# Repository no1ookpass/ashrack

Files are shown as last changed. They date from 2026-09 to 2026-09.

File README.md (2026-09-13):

# Ashrack

An open source, modular half-rack system for 19" racks. Every module is half a
rack wide and slides into the rack from the front, and each one holds a tray that
slides into it, so the tray can be built to suit whatever goes inside.

## Files

| File | What it is |
|---|---|
| `ashrack-panel.scad` | The front module: panel, mounting ear with the rack screw holes, the skeleton frame that holds a tray, and the joiner tabs |
| `ashrack-tray.scad` | The tray that slides into a module: front face with cut-outs, floor with PCB mounts, styled walls, and an optional removable top |
| `ashrack-common.scad` | Shared rack standards, material and fit dimensions. Included by both parts, so a tray cannot drift out of fit with its module |
| `LICENSE` | MIT, so use it, change it and sell it. The only condition is that the notice travels with the files |

Open either part in OpenSCAD and use the Customizer panel; everything you can
change is listed there. The two parts are separate files, but they include the
same dimension file, so build them with matching `module_units`, `tray_width`
and `tray_depth`. Every file is named `ashrack-`, so the project's parts sort
together in a listing and can't be mistaken for a `tray.scad` from elsewhere.

## How the two halves work

A module is half a 19" rack (241.3 mm), so two of them sit side by side and meet
flush in the middle. Both hands come from one model: set `side` to `left` or
`right` and the body is mirrored with a transform, so there is no second file.

At the non-mounting edge each module has a pair of joiner tabs. The right hand's
pair sits one thickness higher, so the two interleave into a four tab stack that
a single vertical bolt passes through, tying the halves together.

Because a module is really just a slot, the two halves need not match. Each takes
its own `tray_width` and `tray_depth`, so a wide deep tray and a narrow shallow
one can sit side by side in the same rack space — the paired examples below do
exactly that.

## Module inputs (`ashrack-panel.scad`)

| Input | Meaning | Default |
|---|---|---|
| `module_units` | Height in rack units | 2 |
| `tray_offset` | How far the tray slot sits from the mounting edge | 20 mm |
| `tray_depth` | How deep a tray the slot takes | 150 mm |
| `tray_width` | Tray width. **0 prints a blank panel**, with no slot at all | 150 mm |
| `side` | Which hand to build | left |
| `ear_thickness` | Mounting ear thickness, as a multiple of the panel | 5 |
| `screw_holes` | Rack screws per unit: 1 centre, 2 outer pair, 3 all three | 3 |

Rack screw holes follow EIA-310: 6.35, 22.225 and 38.1 mm above each unit's
lower edge, so the outer holes sit near the panel edges.

## Tray inputs (`ashrack-tray.scad`)

| Input | Meaning | Default |
|---|---|---|
| `module_units`, `tray_width`, `tray_depth` | Must match the module it goes in | 2, 150, 150 |
| `side_style`, `back_style`, `top_style` | `solid`, `slits` or `skeleton` for each wall | skeleton |
| `top_removable` | Build the top in, or print it as its own part | false |
| `part` | Which piece to build: `body` or `top` | body |
| `handle_sides` | `none`, `rail`, `centre` or `both` | none |
| `handle_type` | `loop` (upright half donut pull) or `knob` | loop |

Handles are named from the module's mounting edge: `rail` is the edge that
screws to the rack, `centre` faces the middle of the rack. Left and right flip
with the hand, so they are no good as names.

### Two lists you edit in the file

The Customizer cannot take a list of shapes: it only accepts flat vectors of up
to four numbers. So the front cut-outs and the floor mounts live in the file,
where they can be any length. Both are commented in place.

```scad
// ["rect", x, z, width, height]  or  ["circle", x, z, diameter, 0]
// (x, z) is the centre, in mm from the bottom left of the front face.
front_cutouts = [
    ["rect",   52, 40, 25, 21],   // ethernet jack
    ["rect",   82, 40, 25, 21],   // ethernet jack
    ["circle", 105, 40,  8,  0],  // LED
];

// [x, y], then height, boss diameter and screw as you need them
pcb_mounts = [[12, 12], [138, 12], [12, 60, 10], [138, 60, 10]];
```

Keep cut-outs clear of the handles: a handle sits `HANDLE_INSET` in from its
edge and half way up the face, and blocks a band around that point — roughly
+/- 4 mm across and +/- 14 mm up and down — and there is no guard against the two
colliding.

`tray()` also takes the two lists, the two handle settings and the two roof settings as arguments —
`cutouts`, `mounts`, `handle_sides`, `handle_type`, `top_style` and `top_removable` — so a build
script can hand over its own without touching this file's defaults:

```scad
tray(units = 1, width = 180, depth = 150, cutouts = my_cutouts, mounts = my_mounts,
     handle_sides = "rail", handle_type = "loop", top_removable = true);
```

That is how a downstream project keeps its build data in its own repo: define the lists there, hand
them over, and the library stays free of any one build's numbers.

Size the keep-out to the handle you picked: a knob is ~16 mm across, a loop spans
`HANDLE_LOOP_OPENING` plus its feet (28 mm) up and down the face and stands further off
it, so the band a cut-out has to avoid is taller with a loop than the `+/- 14 mm` above
suggests.

## Examples

Everything below is these files with the settings noted. The three scripts in
`examples/` show how the parts go together: one for a pair of modules, one for a
module with its tray, and one for both halves with their trays.

### Module

| | |
|---|---|
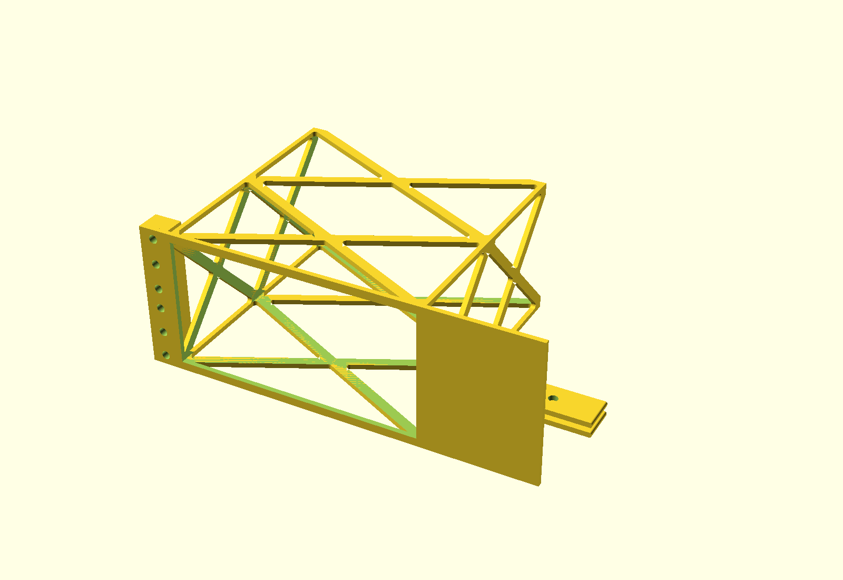
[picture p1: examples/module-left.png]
2U module, left hand
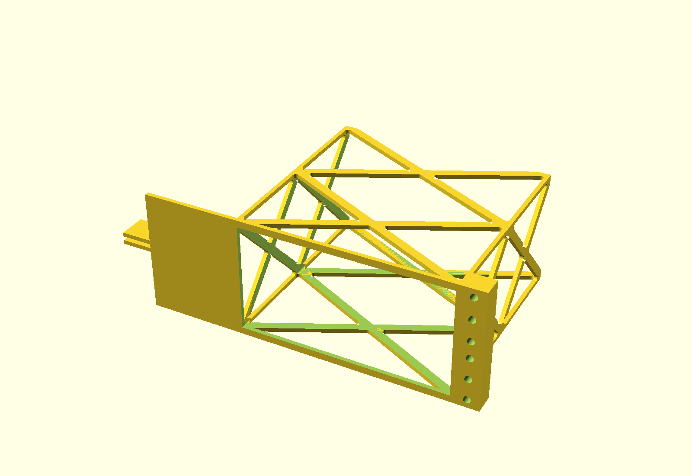
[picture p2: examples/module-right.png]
2U module, right hand
|  |  |
| **Left hand**, the default: mounting ear with the rack screw holes, skeleton tray frame behind the panel | **Right hand**, `side = "right"`. The same model mirrored, so there is no second file |
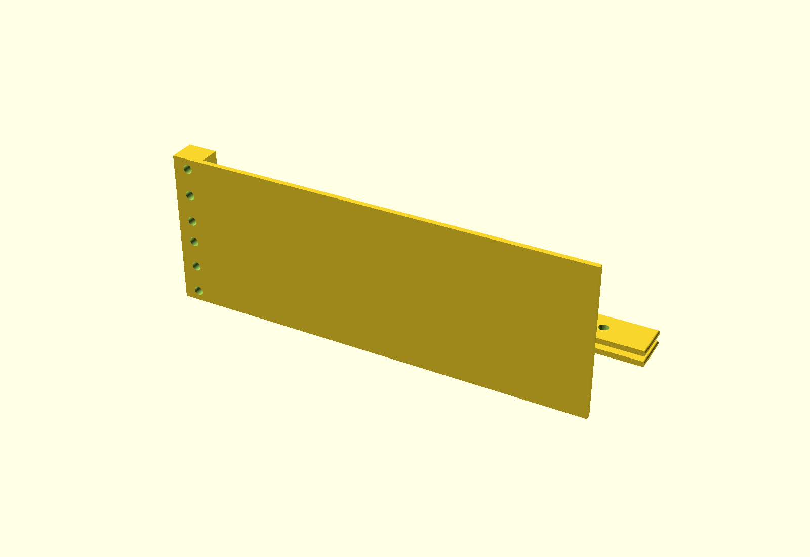
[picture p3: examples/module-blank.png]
Blank panel
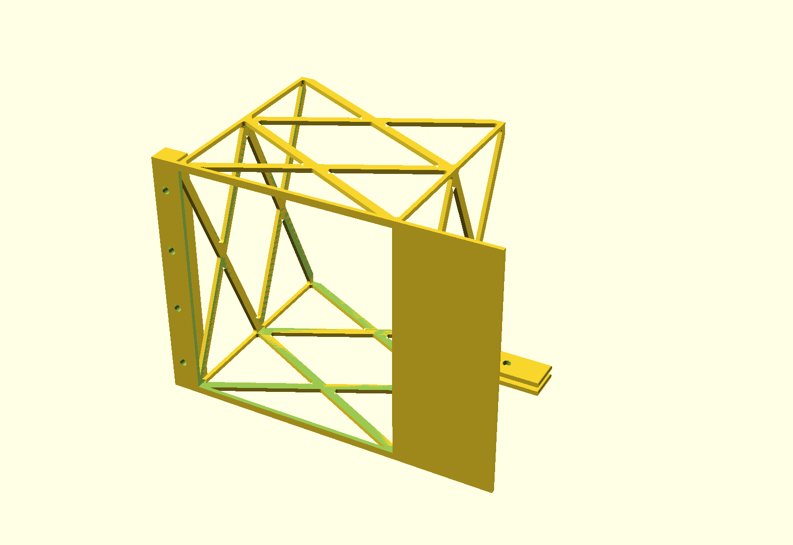
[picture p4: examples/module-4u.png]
4U module, one hole per unit
|  |  |
| `tray_width = 0`: a **blank panel**, no slot and no frame at all | `module_units = 4` with `screw_holes = 1`: one centre hole per unit |
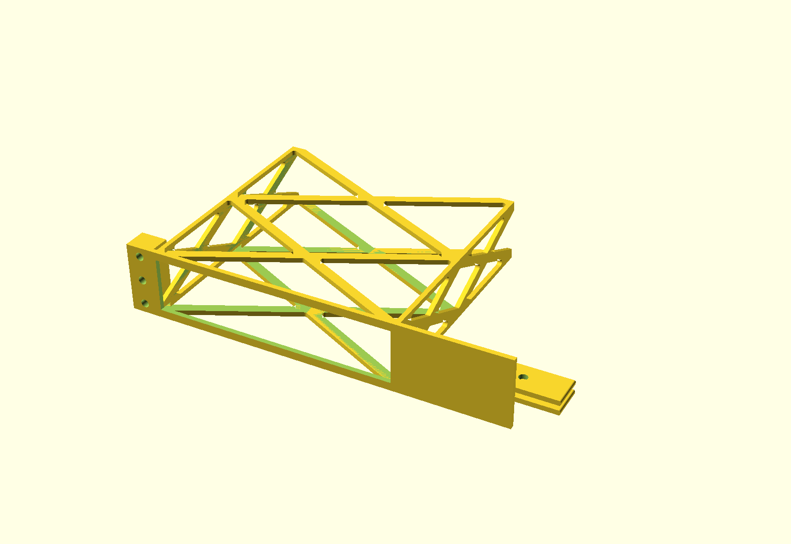
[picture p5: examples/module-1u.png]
1U module
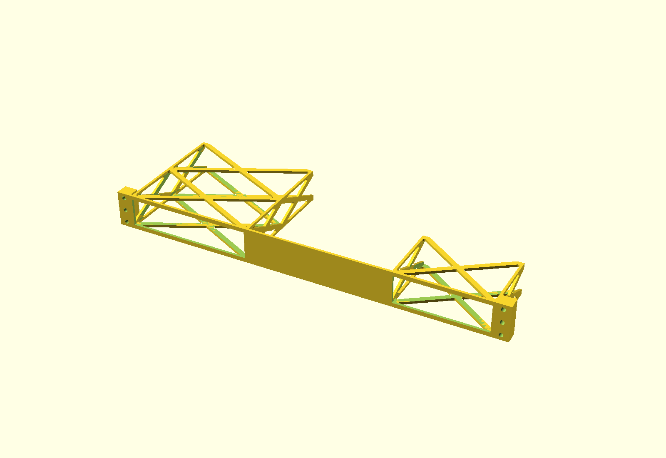
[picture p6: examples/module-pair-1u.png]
Two 1U halves joined
|  |  |
| `module_units = 1`: a single unit tall | The pair again at 1U, still with two different slot sizes |

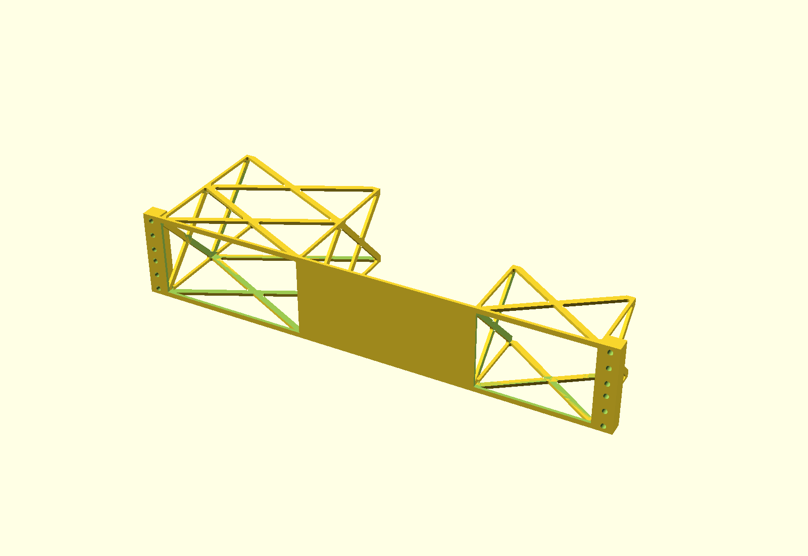
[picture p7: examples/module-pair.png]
Two halves joined


*Two halves butted at the centre of the rack. The panels meet flush, and the
joiner tabs interleave into one stack for a single vertical bolt — see
`examples/module-pair.scad`.*

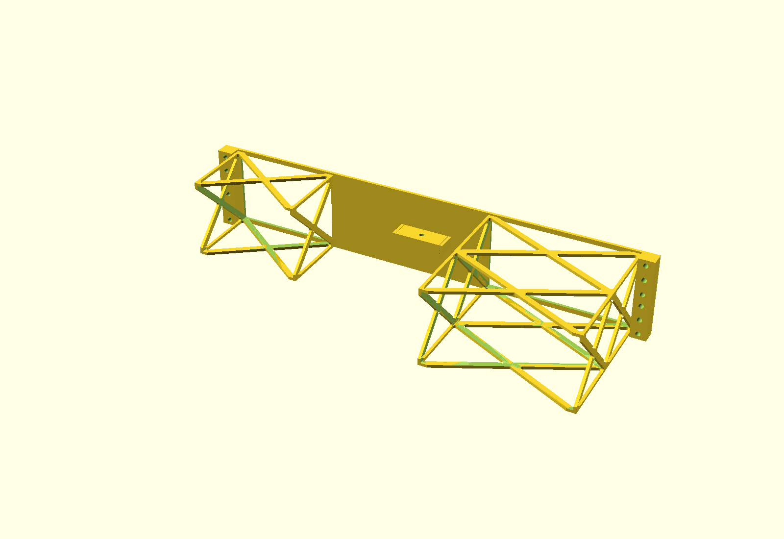
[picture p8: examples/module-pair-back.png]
The same two halves from behind


*The same pair from behind, where you can see each half is its own slot: 150 x
150 mm on the rail side, 110 x 80 mm on the centre side. Nothing ties the two
sizes together — `examples/module-pair-1u-back.png` shows the same pair at 1U, and
`examples/pair-assembly-back.png` the same idea with trays in place.*

### Tray

| | |
|---|---|
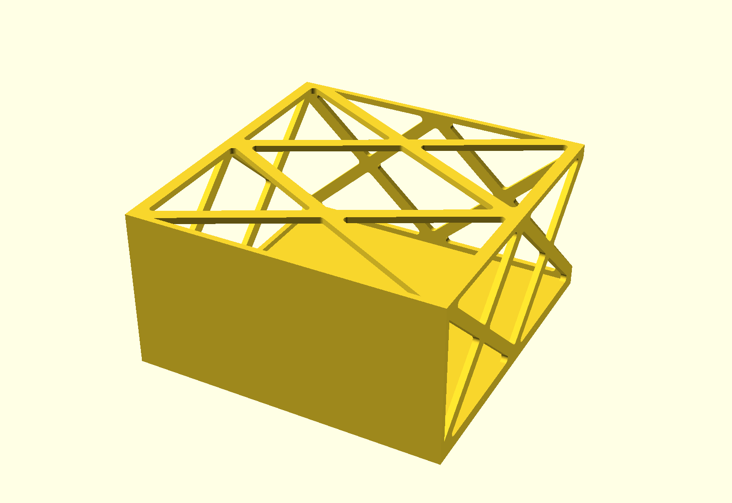
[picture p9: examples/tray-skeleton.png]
Skeleton tray
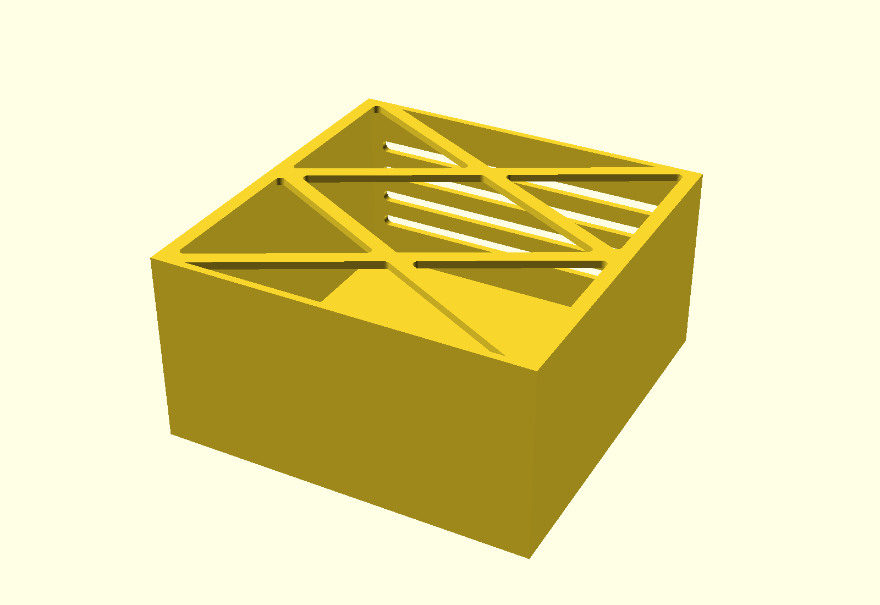
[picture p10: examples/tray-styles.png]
Tray with mixed wall styles
|  |  |
| The default: skeleton sides, back and top | `side_style = "solid"` with `back_style = "slits"`: each wall is chosen separately |
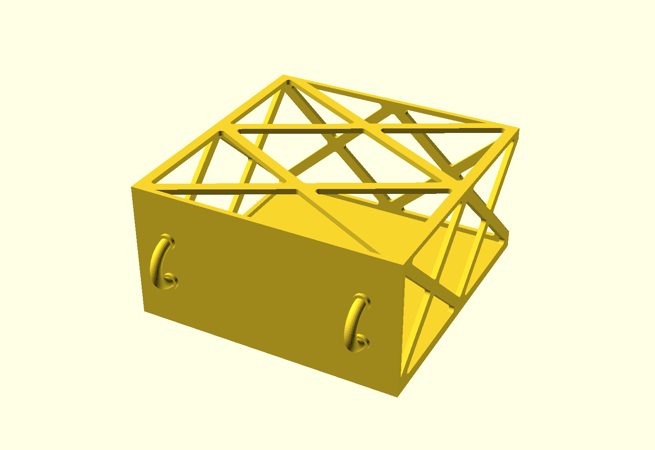
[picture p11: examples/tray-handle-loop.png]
Loop handles
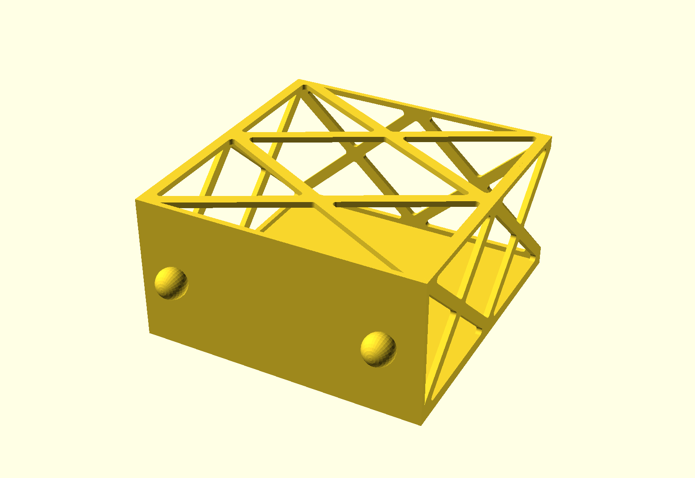
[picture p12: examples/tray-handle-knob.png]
Knob handles
|  |  |
| `handle_sides = "both"`, `handle_type = "loop"`: upright half donut pulls | The same sides with `handle_type = "knob"` |
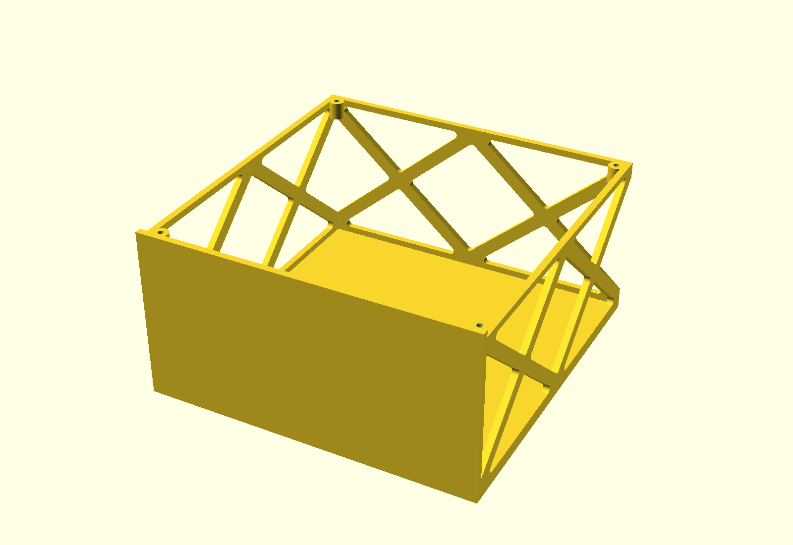
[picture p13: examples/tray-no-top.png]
Body for a removable top
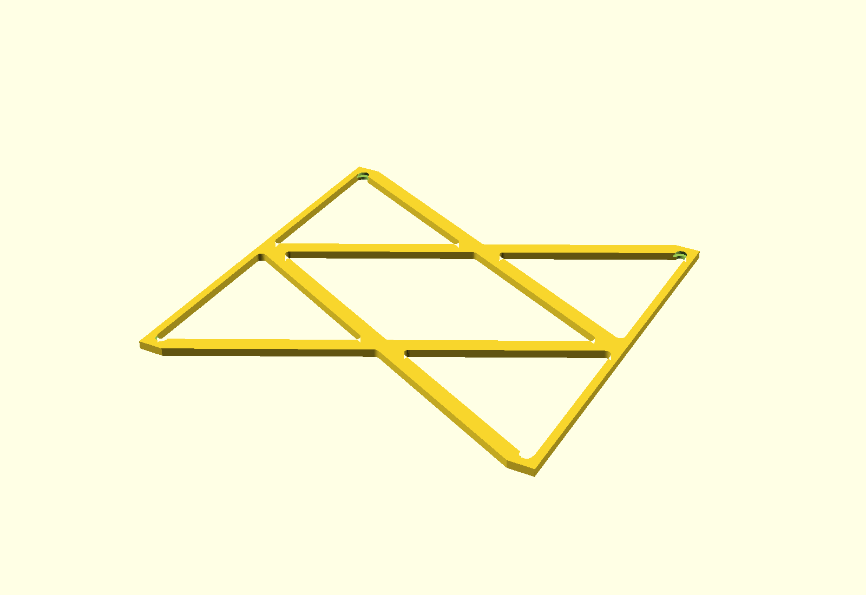
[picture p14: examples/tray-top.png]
The removable top on its own
|  |  |
| `top_removable = true`: the body, walls stopping short with screw bosses in the corners | `part = "top"`: the top prints as its own part, with countersunk screw holes |
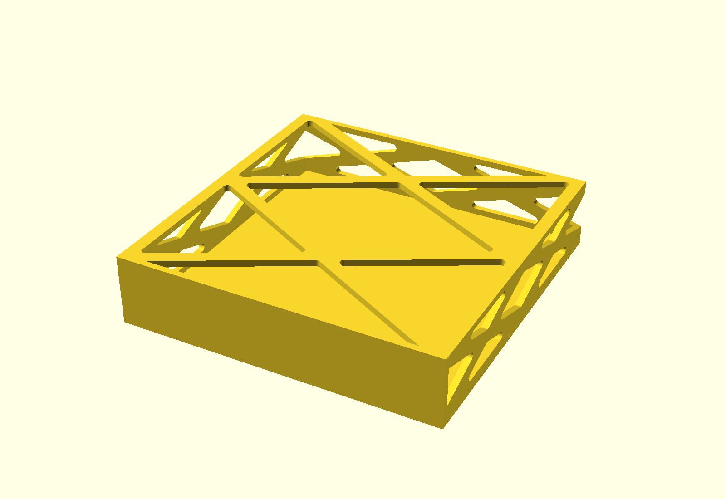
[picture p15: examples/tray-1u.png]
1U tray
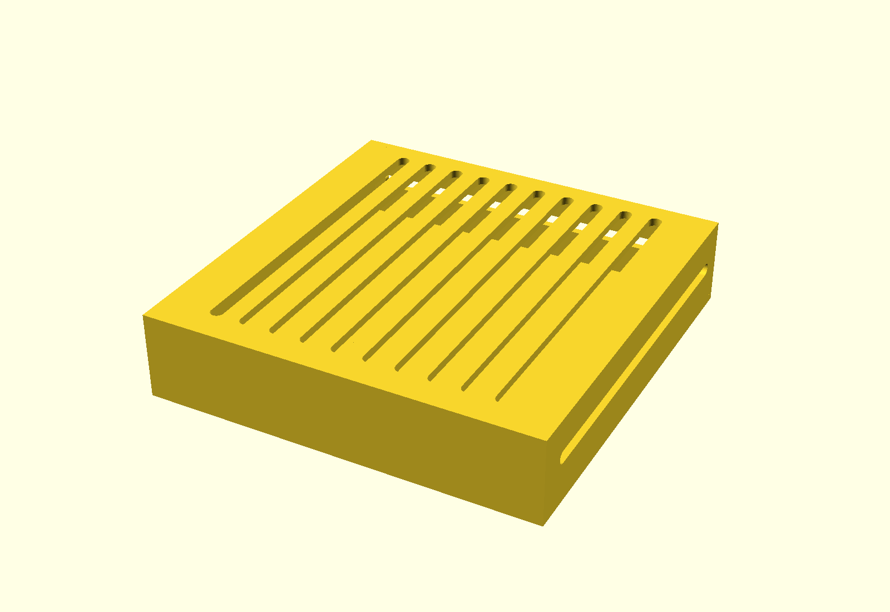
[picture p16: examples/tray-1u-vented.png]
1U tray, every wall slitted
|  |  |
| `module_units = 1`: a shallow tray, but `tray_depth` still sets how far back it reaches | All three wall styles set to `"slits"` |
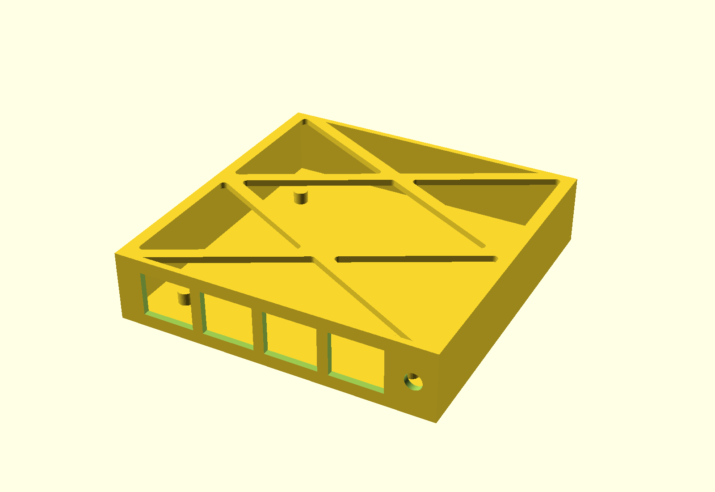
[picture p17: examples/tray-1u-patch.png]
1U patch panel tray
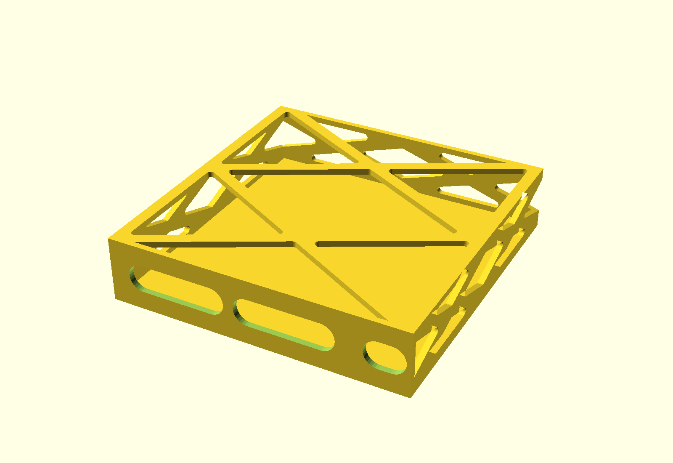
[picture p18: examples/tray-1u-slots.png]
1U tray with cable slots
|  |  |
| A patch panel front: four ethernet openings and an LED, with solid walls and PCB mounts behind | Three stadium openings, from the optional sixth cut-out value that rounds a rectangle's corners |
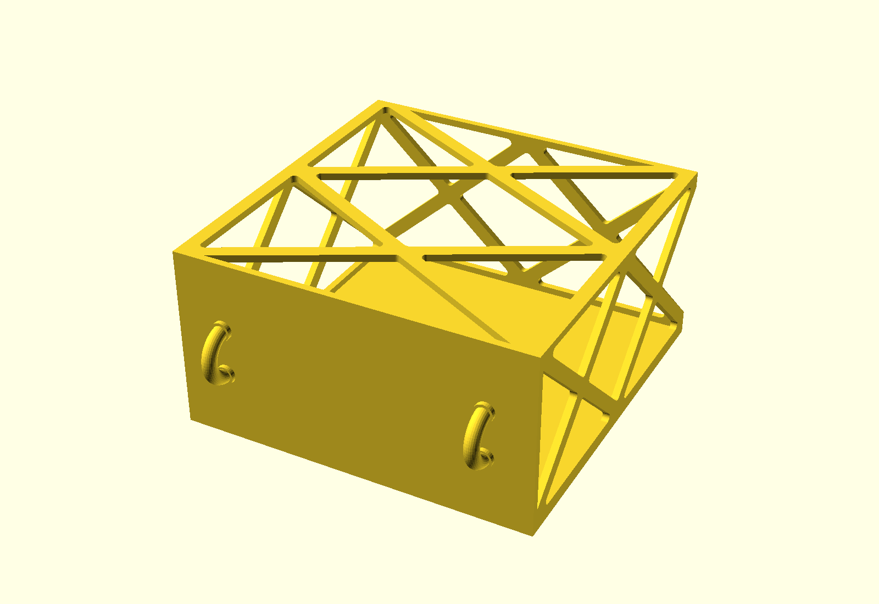
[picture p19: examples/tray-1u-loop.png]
1U tray with loop handles
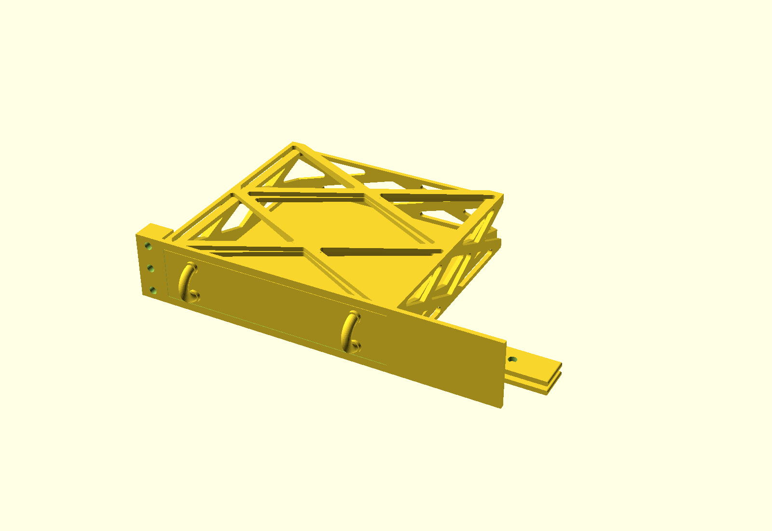
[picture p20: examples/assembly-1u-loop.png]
The same 1U tray in its module
|  |  |
| `handle_sides = "both"`: the upright loop is 28 mm tall, so it sits in the 33 mm face with 2.6 mm to spare top and bottom | The same tray slid into its module, the handle clearing the opening |

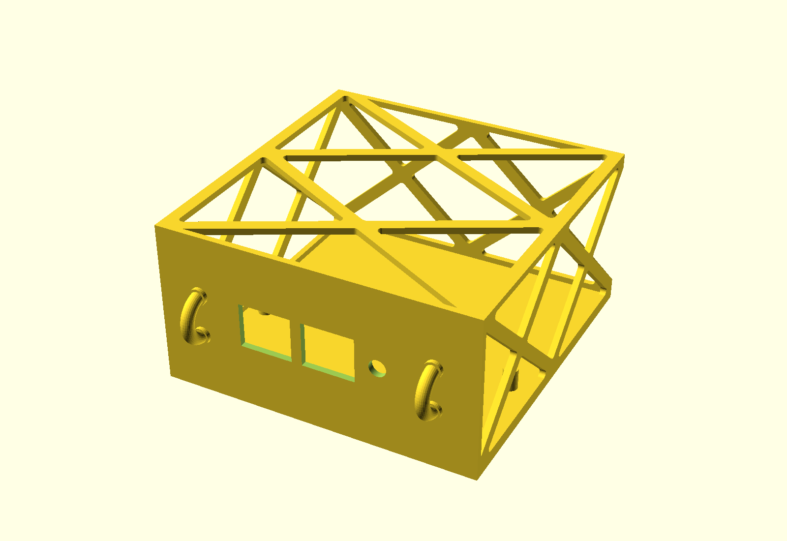
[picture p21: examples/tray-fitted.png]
Tray with cut-outs, mounts and handles


*Everything at once: two ethernet openings and an LED in the front face, four PCB
standoffs on the floor with the back pair taller to clear a connector, and
handles on both sides.*

### Together

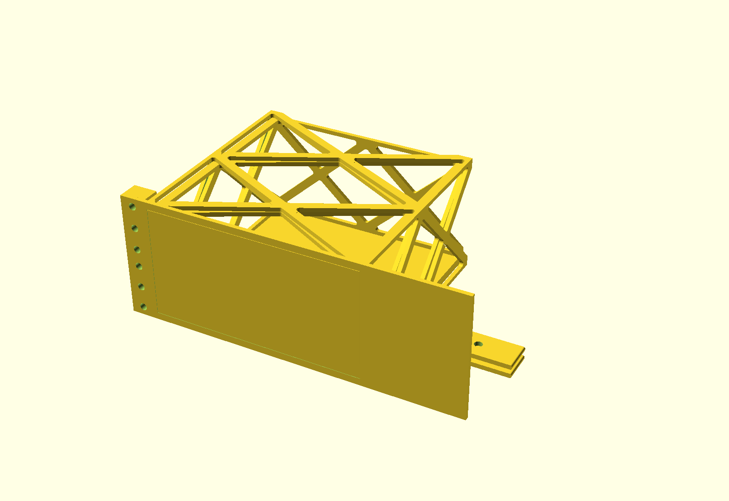
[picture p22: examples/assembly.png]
A tray slid into its module


*`examples/assembly.scad`: the module, with the tray placed by `tray_position()`
so it runs exactly where it slides.*

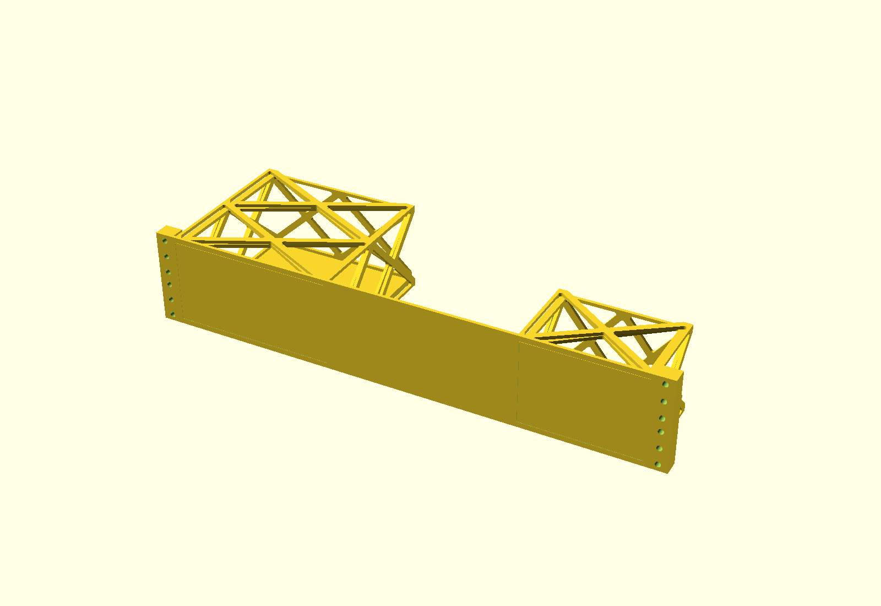
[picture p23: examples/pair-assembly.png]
Both halves with their own trays


*Both halves at once, each with a tray built to its own slot: 150 x 150 mm on the
left, 110 x 80 mm on the right. The right half and its tray are the same models
mirrored, so the tray runs into the slot from the other side.*

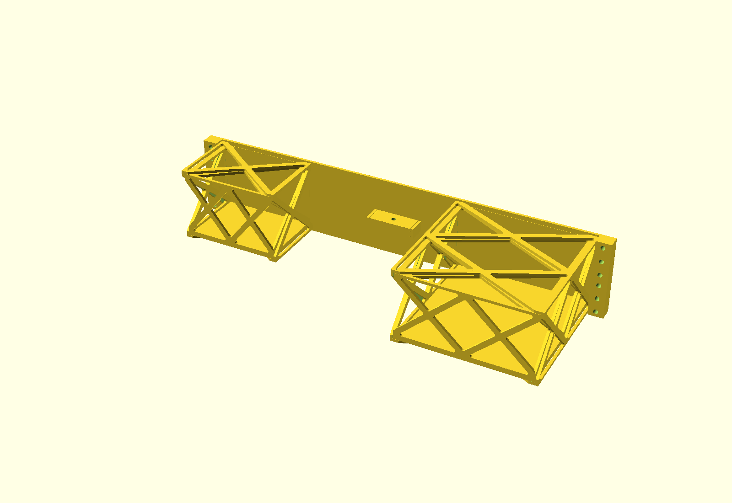
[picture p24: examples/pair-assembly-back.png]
The same pair of assemblies from behind


*From behind: the two trays side by side, each sized to the slot holding it.*

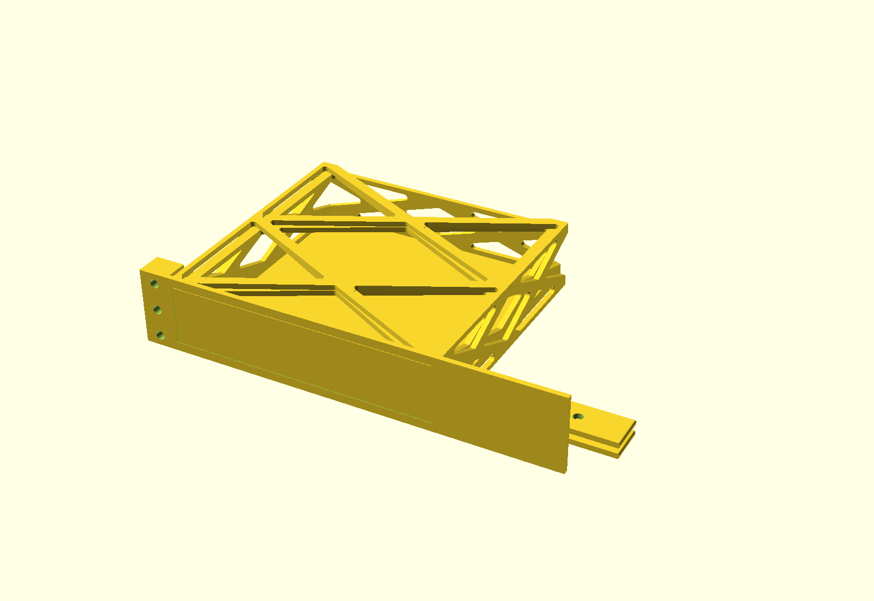
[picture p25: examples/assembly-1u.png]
A 1U module with its tray


*The same assembly at `module_units = 1`, module and tray together.*

## Rendering

```
openscad -o module.stl ashrack-panel.scad
openscad -o tray.stl   ashrack-tray.scad
openscad -o top.stl    -D 'top_removable=true' -D 'part="top"' ashrack-tray.scad
```

To check a tray in its module, place it with the helper the tray provides:

```scad
use <ashrack-panel.scad>
use <ashrack-tray.scad>
half_rack_module(2, 20, 150, 150, "left");
translate(tray_position(20)) tray();
```

The tray is built to the module's opening less a `TRAY_SLIDE_CLEARANCE`, so that
placement leaves 0.25 mm per side. If your printer needs more room, that one
constant is the knob.

`tray()` also takes the size it should be built to, so one script can make any
number of differently sized trays:

```scad
// tray(units, width, depth) — the same numbers the module was built with
tray();                            // the Customizer's tray, 2U x 150 x 150
tray(units = 1, width = 110);      // 1U, 110 wide, 150 deep
tray(width = 110, depth = 80);     // 2U, 110 wide, 80 deep
```

The same goes for `removable_top()`, so a body and its own top always match.

To see the back of a part, render it from the other side by turning the camera
to the opposite azimuth:

```
openscad -o back.png --camera=0,0,0,58,0,208,0 --projection=p examples/pair-assembly.scad
```

## Printing

- **Module**: print it panel face down. The frame rises off the bed and needs no
  support.
- **Tray body**: either orientation is a compromise. Floor down is the natural
  box orientation with a solid base, but leaves the handles as horizontal
  overhangs; front face down prints the handles and cut-outs cleanly, at the cost
  of the floor and walls becoming tall thin fins. The knob is the more forgiving
  handle either way, and a loop printed front-down has a bridge at the top of its
  arch.
- **Removable top**: print it flat, countersinks up.
- **Roof — the part that decides the tray's print.** Built into the body
  (`top_removable = false`, the default) the roof spans the empty tray: a 3 mm rail plus its
  cross-bars bridging the full depth — ~147 mm at 150 deep. A slicer classifies a span between two
  walls as a *bridge*, not an overhang, so it will not scaffold it; it slows down and the rail sags.
  Turning supports on is worse: the scaffold fills the drawer you then have to reach into with
  pliers. **Print the top as its own part** (`top_removable = true`) — the body is then open-topped
  with nothing overhanging anywhere, and the roof is a flat panel. That is the only way to get a
  1U tray out with zero supports.

## Hardware

| Where | Fastener |
|---|---|
| Rack mounting | M5 (5.2 mm clearance holes) |
| Joiner tabs | One M5 bolt through the 12 mm tab stack, with washers — the tabs are plain clearance holes, so any long enough bolt works |
| Removable top | Four M3 self-tapping screws into printed bosses, heads countersunk flush |
| PCB mounts | M3 self-tapping into the standoffs, pilot holes are blind |

## Notes

- The lists are the only place you have to write code. If you extend them, note
  that OpenSCAD 2021.01's `for` loop needs `=`, not `in`.
- Every cut-out and mount is bounds checked: an out of range entry fails the
  build with a message rather than printing a broken part.

## Licence

MIT — see [`LICENSE`](LICENSE). Use it, change it, print it, sell it, put it in a
product. There is no fee and no permission to ask for, and nothing obliges you to
credit anyone in your own docs or on the part; the one condition is that the
copyright notice and the licence text travel with the files.

That covers the design files and the code. What you print from them is yours.

Built something with ashrack? A link back is welcome, not required.

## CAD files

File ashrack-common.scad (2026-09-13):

// SPDX-License-Identifier: MIT
// Copyright (c) 2026 no1ookpass
//
// Ashrack common - shared rack standards, fit dimensions and styling.
//
// Included by the front panel (ashrack-panel.scad) and by the tray that slides
// into it (ashrack-tray.scad), so the two can never drift apart: everything that
// decides whether a tray fits its module lives here.

$fn = 64;

// Standard 19" EIA rack dimensions - fixed, do not customise.
RACK_UNIT = 44.45;
RACK_WIDTH = 482.6;
RACK_MOUNT_HOLE_SPACING = 465.1;

// Material.
PANEL_THICKNESS = 3;
PANEL_HEIGHT_CLEARANCE = 0.8;
RAIL_THICKNESS = 3;
WALL_THICKNESS = 3;

// Panel height for a given number of rack units.
function module_height(units) = units * RACK_UNIT - PANEL_HEIGHT_CLEARANCE;

// The tray channel as the module frames it. A tray has to fit inside these.
TRAY_EDGE_MARGIN = 5;
TRAY_FIT_CLEARANCE = 0.4;
function opening_width(tray_width) = tray_width + 2 * TRAY_FIT_CLEARANCE;
function opening_height(units) = module_height(units) - 2 * TRAY_EDGE_MARGIN;

// Below this tray width the channel is too narrow to frame - the join fillet
// alone would fill it in - so the module prints as a blank panel with no slot.
// Keeps the width slider usable all the way down to 0.
MIN_TRAY_WIDTH = 10;

// Criss-cross styling, shared so a tray's walls match the frame holding it.
FRAME_PITCH = 70;
FRAME_BAR_SPREAD = 2;
JOIN_FILLET = 2;

// Closing pass: fills concave joins with a radius so crossings read as ")("
// rather than "><". Wrap it around a flat panel drawn in 2D.
module fillet_joins(radius = JOIN_FILLET) {
    offset(r = -radius, $fn = 32)
        offset(r = radius, $fn = 32)
            children();
}

// A panel drawn flat: edge rails with criss-cross bars braced between them and
// the joins filleted. u runs along the panel, v across it, and brace_span is the
// clear distance the bars span (use the full width to brace wall to wall).
module braced_panel(u_len, v_len, brace_span) {
    r = RAIL_THICKNESS;
    cells = max(1, round(u_len / FRAME_PITCH));
    cell = u_len / cells;
    bar_length = sqrt(cell * cell + brace_span * brace_span) + r;
    angle = atan2(brace_span, cell);

    // Trimmed to the outline so the scooped joins and the bar overshoot cannot
    // poke outside the panel.
    intersection() {
        fillet_joins()
            union() {
                // Edge rails, running the full length.
                for (v = [1, -1])
                    translate([0, v * (v_len - r) / 2])
                        square([u_len, r], center = true);

                // Criss-cross bars, braced across the panel.
                for (i = [0 : cells - 1])
                    for (side = [1, -1])
                        translate([cell * (i + 0.5) - u_len / 2, 0])
                            rotate(side * angle)
                                square([bar_length, FRAME_BAR_SPREAD * r], center = true);
            }

        square([u_len, v_len], center = true);
    }
}

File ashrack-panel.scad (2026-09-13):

// SPDX-License-Identifier: MIT
// Copyright (c) 2026 no1ookpass
//
// Ashrack panel - the front of one half of the rack.
//
// Panel, mounting ear with the rack screw holes, the skeleton frame a tray
// slides into, and the joiner tabs that tie the two halves together. Both hands
// come from the same geometry, mirrored with a transform, so there is never a
// second model file to maintain.
//
// Local coordinate system of the module body:
//   X = 0 at the rack mounting edge, growing towards the rack centre
//   Y = 0 at the front face, growing backwards into the rack
//   Z = 0 at the bottom of the panel

include <ashrack-common.scad>

/* [Module] */

// Module height in rack units
module_units = 2; // [1:1:8]

// Tray offset from the mounting edge (mm)
tray_offset = 20; // [0:1:220]

// Tray depth (mm)
tray_depth = 150; // [10:1:600]

// Tray width (mm). Zero makes this a blank panel: no opening, no tray frame.
tray_width = 150; // [0:1:220]

// Rack side this module mounts to
side = "left"; // [left, right]

// Mounting ear thickness, as a multiple of the panel thickness. Measured
// front to back from the panel face, so 1x leaves no ear material.
ear_thickness = 5; // [1:1:8]

// Rack screw holes per rack unit: 1 centre, 2 outer pair, 3 all three
screw_holes = 3; // [1:1:3]

/* [Hidden] */

// The ear bridges the mounting edge to the tray frame, so its width follows the
// tray offset and always meets the tray container. Only its thickness is scaled
// by the user (front to back, as a multiple of the panel).
EAR_THICKNESS = ear_thickness * PANEL_THICKNESS;
EAR_EDGE_MARGIN = 3;

// Rack mounting hole geometry. The diameter is a standard screw clearance - M5
// is the common 19" rack screw (M6 clearance is 6.4, 10-32 is 4.9).
MOUNT_HOLE_D = 5.2;
MOUNT_HOLE_X = (RACK_WIDTH - RACK_MOUNT_HOLE_SPACING) / 2;

// EIA-310 rack holes sit this far above the unit's lower edge: the outer pair
// close to the panel edges, the middle one on the unit centre line. 15.875 is
// the spacing between holes within a group, not a position.
MOUNT_HOLE_CENTRE = 22.225;
MOUNT_HOLE_OUTER = [6.35, 38.1];
MOUNT_HOLE_ALL = [6.35, 22.225, 38.1];
MOUNT_HOLE_EDGE_MARGIN = 4;

// Hole offsets within a unit for the requested number of holes per unit.
function mount_hole_offsets(per_unit) =
    per_unit <= 1 ? [MOUNT_HOLE_CENTRE]
    : per_unit == 2 ? MOUNT_HOLE_OUTER
    : MOUNT_HOLE_ALL;

// Hole depth follows the ear thickness: the hole passes through the panel and
// through whatever ear material sits behind it.
MOUNT_HOLE_DEPTH = EAR_THICKNESS;

// Joiner. Two tabs on the non-mounting edge, stacked in Z with a gap of one tab
// thickness between them, each with a single bolt hole through its middle. The
// two hands stack their pairs one thickness apart, so a left and a right module
// interleave into a four tab stack with one bolt through it. The bolt runs
// vertically, so it carries the load directly.
JOINER_INSET = 25;                          // room the tabs take up inside the edge
JOINER_REACH = 25;                          // how far they run out past it
JOINER_PLATE_THICKNESS = RAIL_THICKNESS;    // tab thickness, and the gap in the pair
JOINER_PLATE_DEPTH = 20;                    // tab depth front to back
JOINER_SPINE = RAIL_THICKNESS;              // rib at the root tying the tabs in
JOINER_BULKHEAD = JOINER_INSET + JOINER_SPINE;   // total room the joiner needs
JOINER_TAB_ROUND = 1;                       // lead-in round on the tab edges

// Half a 19" rack. Two of these meet flush at the centre of the rack, which is
// what lets the joiner tabs line up on each other.
MODULE_WIDTH = RACK_WIDTH / 2;

// Standard mounting hole heights for a panel of the given rack unit count and
// hole count. The panel is centred in its rack space, so the pattern shifts too.
function mount_hole_positions(units, per_unit) =
    let (h = module_height(units), space_bottom = -PANEL_HEIGHT_CLEARANCE / 2)
    [ for (u = [0 : units - 1])
        for (offset = mount_hole_offsets(per_unit))
            let (zz = u * RACK_UNIT + offset + space_bottom)
            if (zz > MOUNT_HOLE_EDGE_MARGIN && zz < h - MOUNT_HOLE_EDGE_MARGIN)
                zz ];

// One face of the tray frame, drawn flat so the joins can be filleted in 2D.
// u runs along the tray depth, v runs across the face. The fillet only ever moves
// material in the face plane, so it adds no height and cannot grow into the tray
// channel.
module face_pattern(depth, span, rise) {
    braced_panel(depth, span, rise);
}

// Open tray container: four corner rails braced by a criss-cross lattice on each
// face, instead of solid walls. The frame assumes nothing about what gets slid
// into it, so it stays open and uses minimal material.
module tray_frame(offset, depth, opening_w, opening_h) {
    r = RAIL_THICKNESS;
    y0 = PANEL_THICKNESS;
    x0 = offset - r;
    z0 = TRAY_EDGE_MARGIN - r;
    frame_w = opening_w + 2 * r;
    frame_h = opening_h + 2 * r;
    mid_y = y0 + depth / 2;

    // Side faces: pattern lies in the YZ plane, extruded across X. The pattern is
    // symmetric across v, so the mirrored v axis is harmless.
    for (x = [x0 + r / 2, x0 + frame_w - r / 2])
        translate([x, mid_y, z0 + frame_h / 2])
            rotate([0, 0, 90])
                rotate([90, 0, 0])
                    linear_extrude(height = r, center = true)
                        face_pattern(depth, frame_h, opening_h);

    // Top and bottom faces: pattern lies in the XY plane, extruded across Z.
    for (z = [z0 + r / 2, z0 + frame_h - r / 2])
        translate([x0 + frame_w / 2, mid_y, z])
            rotate([0, 0, 90])
                linear_extrude(height = r, center = true)
                    face_pattern(depth, frame_w, opening_w);
}

// The two interleaving tabs on the non-mounting edge, plus the rib that ties
// them back to the panel. Both hands carry a pair; because the right hand's pair
// sits one thickness higher, a left and a right module side by side form a four
// tab stack with a single vertical bolt through it.
module joiner_tabs(units, rack_side) {
    h = module_height(units);
    t = JOINER_PLATE_THICKNESS;
    x0 = MODULE_WIDTH - JOINER_INSET;
    z_base = h / 2 - 2 * t;
    z_shift = rack_side == "right" ? t : 0;

    // Root rib: without it the upper tab of each pair would be left floating. It
    // has to sit inboard of the tabs, or it would fill the other hand's slots.
    translate([x0 - JOINER_SPINE, PANEL_THICKNESS, z_base])
        cube([JOINER_SPINE, JOINER_PLATE_DEPTH, 4 * t]);

    for (i = [0, 1])
        translate([x0, PANEL_THICKNESS, z_base + t / 2 + z_shift + 2 * i * t])
            difference() {
                // Drawn as a cross-section and extruded, so the corners facing
                // along the tab come out rounded: those are the edges that meet
                // the other hand's tabs, and rounding them helps them feed in.
                rotate([-90, 0, 0])
                    linear_extrude(height = JOINER_PLATE_DEPTH)
                        translate([JOINER_INSET, 0])
                            offset(r = JOINER_TAB_ROUND)
                                offset(r = -JOINER_TAB_ROUND)
                                    square([JOINER_INSET + JOINER_REACH, t], center = true);

                // One bolt hole through the middle of every tab.
                translate([JOINER_INSET, JOINER_PLATE_DEPTH / 2, -t / 2 - 1])
                    cylinder(h = t + 2, d = MOUNT_HOLE_D);
            }
}

// One handed module, built with its mounting edge on X = 0.
module module_body(units, offset, depth, width, rack_side) {
    h = module_height(units);
    opening_h = h - 2 * TRAY_EDGE_MARGIN;
    opening_w = width + 2 * TRAY_FIT_CLEARANCE;

    // Anything from zero up to the minimum prints as a blank panel: nothing is
    // going to slide into a channel that narrow anyway, and framing it would
    // just fill the channel in with fillet material.
    trays = width >= MIN_TRAY_WIDTH;

    // Ear reaches from the mounting edge to the outside of the tray frame, so
    // the two always meet whatever the tray offset is.
    ear_width = offset - RAIL_THICKNESS;

    assert(ear_width >= MOUNT_HOLE_X + MOUNT_HOLE_D / 2 + EAR_EDGE_MARGIN,
        "tray_offset is too small: the mounting ear has to be wide enough to carry the rack hole");
    assert(!trays || offset + opening_w + RAIL_THICKNESS <= MODULE_WIDTH - JOINER_BULKHEAD,
        "tray_offset + tray_width would run into the joiner tabs at the inner edge");
    assert(width >= 0, "tray_width cannot be negative");
    assert(depth > 0, "tray_depth must be greater than zero");
    assert(opening_h > 0, "module_units is too small to fit a tray");

    difference() {
        union() {
            // Front panel.
            cube([MODULE_WIDTH, PANEL_THICKNESS, h]);
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

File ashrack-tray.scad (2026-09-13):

// SPDX-License-Identifier: MIT
// Copyright (c) 2026 no1ookpass
//
// Ashrack tray - the drawer that slides into a module's tray slot.
//
// Front and floor are always solid. The side walls, back wall and top can each be
// solid, solid with slits, or a criss-cross skeleton. The front cut-outs and the
// PCB mounts on the floor are both lists you edit in this file, further down.
//
// Coordinates match the module's opening, so the tray drops straight in:
//   X = 0 at the left of the opening, growing right
//   Y = 0 at the front face, growing backwards into the rack
//   Z = 0 at the bottom of the opening

include <ashrack-common.scad>

// Front cut-outs and PCB mounts are lists you edit here in the file. The
// Customizer cannot take a list of shapes (it only accepts flat vectors of up to
// four numbers), so this data lives in code where it can be any length.

/* [Tray] */

// Rack units this tray is built for. Must match the module it goes into.
module_units = 2; // [1:1:8]

// Tray width (mm). Must match the module it goes into.
tray_width = 150; // [10:1:220]

// Tray depth (mm). Must match the module it goes into.
tray_depth = 150; // [10:1:600]

// Side walls
side_style = "skeleton"; // [solid, slits, skeleton]

// Back wall
back_style = "skeleton"; // [solid, slits, skeleton]

// Top: the tray's roof. Built into the body, or removable and screwed on.
top_style = "skeleton"; // [solid, slits, skeleton]
top_removable = false;

// Handles on the front face, and which side of it they go on. The sides are
// named from the module's mounting edge: "rail" is the edge that screws to the
// rack, "centre" faces the middle of the rack. Left and right flip with the
// hand, so they are no good as names.
handle_sides = "none"; // [none, rail, centre, both]

// Handle shape: a half donut pull, or a knob
handle_type = "loop"; // [loop, knob]

// Which part to build. With a removable top the roof is its own part, so print
// the body, then the top.
part = "body"; // [body, top]

/* [Hidden] */

// Slide clearance between the tray and the channel it runs in.
TRAY_SLIDE_CLEARANCE = 0.5;

// Slit styling: slots run along the depth, spaced across the wall.
SLIT_WIDTH = 5;
SLIT_PITCH = 12;
SLIT_BORDER = 8;

// Keep cut-outs this far inside the front face.
FRONT_CUTOUT_MARGIN = 2;

// Handles. They sit on the front face and stand out in front of the rack, so
// they never have to pass through the opening; only the feet bite into the face.
// A loop stands upright, so its opening runs up the face: it takes a band
// HANDLE_LOOP_OPENING + HANDLE_FOOT_D tall, 28 mm, which sits in a 1U face
// (33.15 mm) with 2.6 mm to spare top and bottom. It stands HANDLE_LOOP_OPENING/2
// + HANDLE_TUBE, 13 mm, off the face.
HANDLE_INSET = 20;              // handle centre, in from the tray's edge
HANDLE_LOOP_OPENING = 20;       // the loop's span, between its two feet
HANDLE_TUBE = 3;                // half donut tube radius
HANDLE_FOOT_D = 8;              // pad where the loop lands on the face
HANDLE_FOOT_T = 2;
HANDLE_BITE = 0.6;              // how far the feet sink into the face
HANDLE_KNOB_D = 16;
HANDLE_STEM_D = 10;
HANDLE_KNOB_H = 12;             // how far the knob stands off the face

// Handle sides, indexed 0 = rail, 1 = centre.
function handle_on(index, sides = handle_sides) =
    sides == "both" ? true
    : sides == "none" ? false
    : sides == "rail" ? index == 0
    : index == 1;

// Removable top: M3 screws, self-tapping into printed bosses. The top and its
// screws stay inside the tray's outer envelope, or the tray would jam in the
// channel it slides into: the roof sits on the rim and the heads sit in
// countersinks, so nothing stands proud of TRAY_H.
TOP_THICKNESS = WALL_THICKNESS;
TOP_BOSS_D = 7;
TOP_BOSS_HEIGHT = 8;
TOP_BOSS_BITE = 1;                   // boss overlap into the walls, so it fuses
TOP_SCREW_PILOT_D = 2.5;             // pilot for a self-tapping M3
TOP_SCREW_CLEARANCE_D = 3.4;
TOP_SCREW_HEAD_D = 6.2;
TOP_SCREW_HEAD_DEPTH = 1.7;

// Front cut-outs: any number of openings in the front face, from zero up.
//
//   ["rect",   x, z, width, height]          a rectangular opening
//   ["circle", x, z, diameter, 0]            a round opening
//   ["rect",   x, z, width, height, radius]  a 6th value rounds the corners
//
// (x, z) is the centre of the opening, in mm from the bottom left corner of the
// front face. The face is TRAY_W wide and TRAY_H tall, and every opening must
// stay FRONT_CUTOUT_MARGIN inside it, so the usable range is roughly
// x = 2..TRAY_W-2 and z = 2..TRAY_H-2. A corner radius of half the shorter side
// turns the rectangle into a stadium slot (handy for connectors on flying leads).
//
// The two 1" ethernet openings and an LED for the current build, for example.
// Note where the handles land: each one takes roughly HANDLE_INSET +/- 15 mm, so
// keep cut-outs out of those bands. There is no guard against the two colliding.
//   ["rect",   52, 40, 25, 21],   // ethernet jack 1
//   ["rect",   82, 40, 25, 21],   // ethernet jack 2
//   ["circle", 105, 40,  8,  0],  // LED
front_cutouts = [];

// PCB mounts on the floor: any number of standoffs, from zero up. Each entry adds
// one more override, so you only write what differs from the defaults:
//
//   [x, y]                            default boss, height and screw
//   [x, y, height]                    a taller or shorter standoff
//   [x, y, height, boss_d]            ... and a different boss diameter
//   [x, y, height, boss_d, pilot_d]   ... and a different screw
//
// (x, y) is the centre of the standoff, in mm, measured from the tray's front
// left corner: x across the tray, y back from the front face, so y = 0 is the
// outside of the front face and the floor proper starts at y = PANEL_THICKNESS.
// The floor's usable area runs x = WALL_THICKNESS..TRAY_W-WALL_THICKNESS and
// y = PANEL_THICKNESS..PANEL_THICKNESS+TRAY_D. Defaults come from the PCB_
// constants above.
//
// A 100 x 60 board on four standoffs, with the back pair taller to clear a
// connector, for example:
//   [12, 12], [138, 12], [12, 60, 10], [138, 60, 10]
pcb_mounts = [];

// Tray outside size is derived inside tray() from the numbers it is given, so a
// script can build trays of different sizes to sit side by side. See the bottom
// of this file.

// PCB standoffs on the floor: a boss with a blind pilot hole for a screw. Sized
// per mount from its list entry, falling back to these defaults.
PCB_MOUNT_D = 7;                // boss diameter
PCB_MOUNT_H = 6;                // boss height off the floor
PCB_MOUNT_SINK = 0.6;           // how far the boss sinks into the floor, so it fuses
PCB_MOUNT_FLOOR = 1.5;          // material left under the pilot hole
PCB_SCREW_PILOT_D = 2.5;        // self-tapping M3 by default

// Boss centres for a tray of this width and depth, pulled in far enough to bite
// into both walls at each corner.
TOP_BOSS_INSET = WALL_THICKNESS + TOP_BOSS_D / 2 - TOP_BOSS_BITE;
function top_boss_positions(w, d) = [
    for (x = [TOP_BOSS_INSET, w - TOP_BOSS_INSET])
        for (y = [PANEL_THICKNESS + TOP_BOSS_INSET, PANEL_THICKNESS + d - TOP_BOSS_INSET])
            [x, y]
];

// Where this tray sits inside its module. Handy for checking the fit: place the
// module, then translate the tray by this. The opening already includes the fit
// clearance, so only the slide clearance has to be centred in it.
function tray_position(tray_offset) = [
    tray_offset + TRAY_SLIDE_CLEARANCE / 2,
    0,
    TRAY_EDGE_MARGIN + TRAY_SLIDE_CLEARANCE / 2
];

// A rounded rectangle, centred on the origin. Radius is clamped so that half the
// smaller side gives a circle or a stadium.
module rounded_cutout(width, height, radius) {
    r = min(radius, min(width, height) / 2);
    if (r <= 0.01)
        square([width, height], center = true);
    else
        hull()
            for (sx = [-1, 1])
                for (sz = [-1, 1])
                    translate([sx * (width / 2 - r), sz * (height / 2 - r)])
                        circle(r = r, $fn = 32);
}

// The 2D profile of one front cut-out, taken from its list entry.
module hole_profile(hole) {
    if (hole[0] == "circle")
        circle(d = hole[3], $fn = 64);
    else
        rounded_cutout(hole[3], hole[4], len(hole) > 5 ? hole[5] : 0);
}

// A PCB standoff: a boss on the floor with a blind pilot hole, open at the top.
module pcb_mount(x, y, height, boss_d, pilot_d, w, d) {
    assert(x >= WALL_THICKNESS + boss_d / 2 && x <= w - WALL_THICKNESS - boss_d / 2
        && y >= PANEL_THICKNESS + boss_d / 2 && y <= PANEL_THICKNESS + d - boss_d / 2,
        "a pcb_mount falls outside the floor, or runs into a wall or the front face");

    translate([x, y, WALL_THICKNESS - PCB_MOUNT_SINK])
        difference() {
            cylinder(d = boss_d, h = height + PCB_MOUNT_SINK, $fn = 32);

            translate([0, 0, PCB_MOUNT_FLOOR])
                cylinder(d = pilot_d, h = height - PCB_MOUNT_FLOOR + 0.1, $fn = 24);
        }
}
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

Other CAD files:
ashrack.scad
ashrack_common.scad
examples/assembly.scad
examples/module-pair.scad
examples/pair-assembly.scad
tray.scad

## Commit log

2026-09-10 Initial commit: parametric half rack module with tray support
    [ashrack.scad]
2026-09-10 Make ear thickness a panel-relative parameter
    - Expose ear_thickness as a multiple of the front panel thickness, measured
    front to back, replacing the fixed flange dimension
    - Widen the ear to span the mounting edge to the tray frame so it always
    meets the tray container, driven by the tray offset
    - Derive the rack screw hole depth from the ear thickness, keeping the
    diameter at standard M5 rack screw clearance
    [ashrack.scad]
2026-09-10 Replace solid tray sleeve with a filleted skeleton frame
    - Swap the solid four-wall tray container for open corner rails braced by a
    criss-cross lattice, since the module does not know what will slide into it
    - Build each face flat in 2D and extrude it across the frame thickness, so the
    bars stay flat straps and the frame envelope stays exact
    - Fillet the joins with a closing pass (offset out, then back in) so crossings
    and rail junctions read as ")(" instead of "><"
    - Keep all fillet material in the face plane: no added height on the top and
    bottom faces, and the tray channel is never reduced
    [ashrack.scad]
2026-09-10 Fix rack screw hole positions and make the count selectable
    - Place holes on the EIA-310 pattern: 6.35, 22.225 and 38.1 mm above each
    unit's lower edge. 15.875 is the spacing between holes in a group, not a
    position, so the old code put the holes 9.525 mm too far in from the edges
    - Shift the pattern by half the panel clearance, since the panel floats
    centred in its rack space
    - Add a screw_holes setting per rack unit: 1 centre, 2 outer pair, 3 all three
    [ashrack.scad]
2026-09-10 Allow a zero tray width for a blank panel
    - Extend the tray_width slider down to 0
    - Skip the tray frame, the front opening and the channel keep-out below
    MIN_TRAY_WIDTH, giving a solid panel with the mounting ear instead
    - Treat widths under 10 mm as a blank rather than framing them: the join
    fillet alone fills a channel that narrow, which produced more material
    than a full tray
    - Relax the guards accordingly: reject negative width, keep tray_depth
    positive, and only check the fit against the module when a tray is built
    [ashrack.scad]
2026-09-10 Add joiner tabs so two halves can be bolted together flush
    - Two tabs at the non-mounting edge: 25 mm in from that edge, 25 mm out past
    it, one bolt hole through the middle of each, stacked in Z with a gap of one
    tab thickness between them
    - Right hand's pair sits one thickness higher, so a left and a right module
    interleave into a four tab stack that a single vertical bolt passes through
    - Round the tab edges that meet the opposite hand, drawn as a cross-section, so
    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
    [ashrack.scad]
2026-09-10 Extract shared rack standards into ashrack_common.scad
    - Move the rack standards, material, tray fit dimensions and the criss-cross
    styling into a file both the module and its trays include, so a tray cannot
    drift out of fit with the module that holds it
    - Share the fillet_joins closing pass and the braced_panel pattern, so trays
    match the frame holding them
    - Geometry regression checked: the module is unchanged to the last decimal
    [ashrack.scad, ashrack_common.scad]
2026-09-10 Add the tray that slides into a module's slot
    - Front and floor solid; side walls, back wall and roof each solid, slits or
    criss-cross skeleton
    - Sized from the module's opening less a slide clearance, checked by placing it
    in its module: the intersection is empty
    - Front cut-outs are a file-edited list, since the Customizer only takes flat
    vectors of up to four numbers
    - The roof can also be removable: walls stop one thickness short, four corner
    bosses take M3 self-tapping screws, and the top prints as its own part with
    part = "top". Bosses bite into the walls so they fuse, and countersunk heads
    keep the whole thing inside the tray's envelope
    - One top, not a top and a lid: the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
    [tray.scad]
2026-09-10 Add front-face handles to the tray
    - handle_sides picks which side of the front face carries a handle: rail,
    centre, both or none. Sides are named from the module's mounting edge, since
    left and right flip with the hand, and the tray is placed inside the module's
    own frame, so one tray model works either way round
    - handle_type picks a half donut loop pull or a knob
    - Handles mount on the front face and stand out ahead of the rack, so they never
    pass through the opening: verified no intersection with the module, and the
    tray body still sits inside the opening
    - Loop feet sink into the face so they fuse; the knob is domed so it prints
    without overhang
    [tray.scad]
2026-09-11 Add front cut-outs and PCB mounts as editable lists
    - front_cutouts takes any number of openings, each named by shape:
    ["rect", x, z, width, height] or ["circle", x, z, diameter, 0], with an
    optional 6th value rounding the corners into a stadium slot. A worked example
    (two ethernet openings and an LED) sits in the comments
    - pcb_mounts adds standoffs on the floor, each entry overriding only what it
    needs: [x, y], then height, boss diameter and screw as they are given
    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
    [tray.scad]
2026-09-11 Add a README and a rendered examples gallery
    - README covers what each part is, every Customizer input, the two file-edited
    lists, how to render each part, printing guidance and the hardware list
    - examples/ holds 13 renders plus the two scripts showing the parts going
    together, all linked from the README
    - Move the worked cut-out example clear of the handles, and note in both the
    code and the README that nothing guards the two from colliding
    - Scope .gitignore to the repo root, so examples/ stays tracked while exports
    at the root are ignored
    [assembly.scad, module-pair.scad, tray.scad]
2026-09-11 Build the tray to any size, and pair halves with different trays
    - tray() and removable_top() now take the units, width and depth they should
    be built to. They default to the Customizer's values, so the default parts
    are unchanged (checked: identical volume to the last decimal), but a script
    can now place differently sized trays in differently sized slots
    - The examples show the point of that: the paired scripts put a 150 x 150 mm
    slot on the rail side and a 110 x 80 mm one on the centre side, each with its
    own tray. Verified by placing each tray in its own module: the intersection
    is empty, and each tray comes out to its slot less the slide clearance
    - assembly.scad takes its sl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
    [assembly.scad, module-pair.scad, pair-assembly.scad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]
2026-09-11 Let a build script hand its own cut-outs and mounts to tray()
    [tray.scad]
2026-09-11 Name the file set consistently as ashrack-*
    - ashrack.scad becomes ashrack-panel.scad and tray.scad becomes
    ashrack-tray.scad, so every file in the project shares one convention and the
    three sort together
    - ashrack_common.scad becomes ashrack-common.scad: it was the last file left on
    an underscore, and now nothing looks like a stray file from another project
    - Renamed with git mv, so history follows each file, and every include, use and
    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
    [ashrack-common.scad, ashrack-panel.scad, ashrack-tray.scad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]
2026-09-11 Let a build script choose the tray's handles
    [ashrack-tray.scad]
2026-09-11 Stand the loop handles upright
    - Rotate the loop in the plane of the face, so its long axis runs up the tray
    instead of across it: the bail now reads as a riser you pull straight out,
    rather than a drawer pull lying along the face
    - The upright loop is 9 mm across and 33 mm up, where it was 33 across and 9 up.
    It takes a tall band instead of a wide one, which frees the space either side
    of it: that is where the front cut-outs tend to sit, and the fitted example now
    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
    [ashrack-tray.scad]
2026-09-11 Shrink the upright loops so they sit nicely in a 1U face
    - HANDLE_LOOP_OPENING 24 -> 20 and HANDLE_FOOT_D 9 -> 8: the loop is now 28 mm
    tall overall where it was 33. A 1U face is 33.15 mm, so it sits with 2.6 mm
    clear top and bottom instead of the 0.07 mm it had, and the foot pads no longer
    land flush with the face edges
    - The loop is still 8 mm across and stands 13 mm off the face, so there is room
    behind the tube to pull on. The default tray is untouched at 144,996.2 mm^3,
    and handles on both sides still give an empty intersection with their module
    at both 1U and 2U
    - examples/assembly.scad now takes handle_sides, so one script gives the plain
    assembly as before and a handled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
    [ashrack-tray.scad, assembly.scad]
2026-09-11 Let a build script choose the roof, and say why the roof decides the print
    [ashrack-tray.scad]
2026-09-13 Add an MIT licence
    - LICENSE: the standard MIT text, copyright 2026 no1ookpass, checked word for
    word against a reference copy of MIT before committing
    - README: a Licence section, and a row in the files table. It spells out what
    the licence actually permits, including that nothing in it obliges anyone to
    credit the project in their own docs or on the part: the notice travelling
    with the files is the only condition
    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
    [ashrack-common.scad, ashrack-panel.scad, ashrack-tray.scad]
